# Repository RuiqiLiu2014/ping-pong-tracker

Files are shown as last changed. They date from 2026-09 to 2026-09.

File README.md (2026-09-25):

# Ping Pong Tracker

A ping pong paddle motion tracker, attached to the base of the handle, that sends 6-axis IMU data to a phone app at 1660 Hz via BLE. The phone app saves and displays the data in a readable format, showing hit time, paddle speed, brushing percentage, and more for every shot, allowing users to easily analyze their shot quality and find shortcomings in their swings.

---

## Demo

Watch the video below for a short demo.
<p align="center">
  <a href="https://youtu.be/olZcyWfupK0">
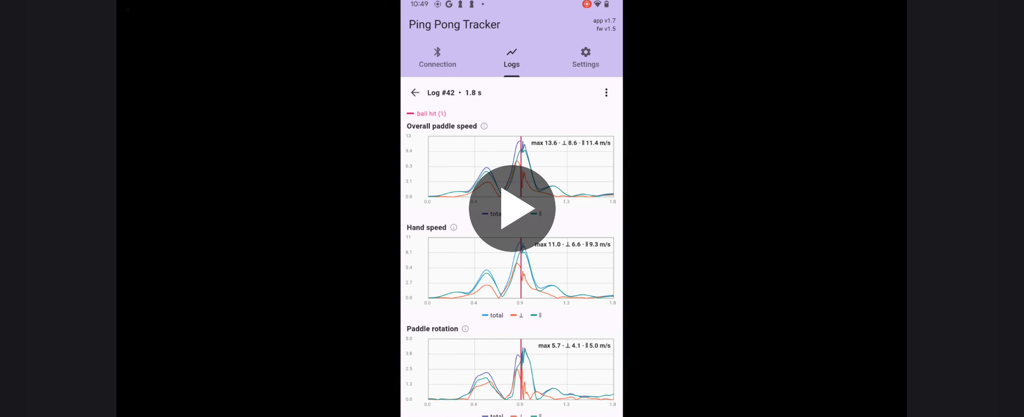
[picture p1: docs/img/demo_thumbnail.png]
Ping Pong Tracker Demo — click to watch
    
  </a>
</p>

---

## Overview

There are sports trackers out there for racket sports, but they tend to be expensive, with ping pong being one of the most expensive as it generally relies on technology embedded within the paddle itself. My goal is to create a budget-friendly alternative that can still accurately track metrics like swing speed, hit timing, and spin. My tracker uses a lightweight 3D printed case, housing a XIAO nRF52840 Sense microcontroller (with onboard 6-axis IMU) soldered to a 100 mAh LiPo battery pack. The whole unit weighs ~7g and is mounted to the base of the handle, and has features as described in the next section.

---

## Features

- Accelerometer and gyroscope streaming at 1660 Hz to accurately capture swing motions
- Automatic hit detection to log data for each shot
- Manual logging mode to log practice swings
- Metrics for every log including overall paddle speed, hand speed, paddle rotation, brushing percentage, face angle, and hit timing—all displayed using interactive graphs
- Rechargeable battery pack via USB-C port
- Straightforward app interface, color themes, light and dark mode, and very flexible settings options

---

## Screenshots

<!-- 2-4 app screenshots. A table keeps them aligned. -->
| Connection screen | Calibration wizard 1 | Calibration wizard 2 |
|---|---|---|
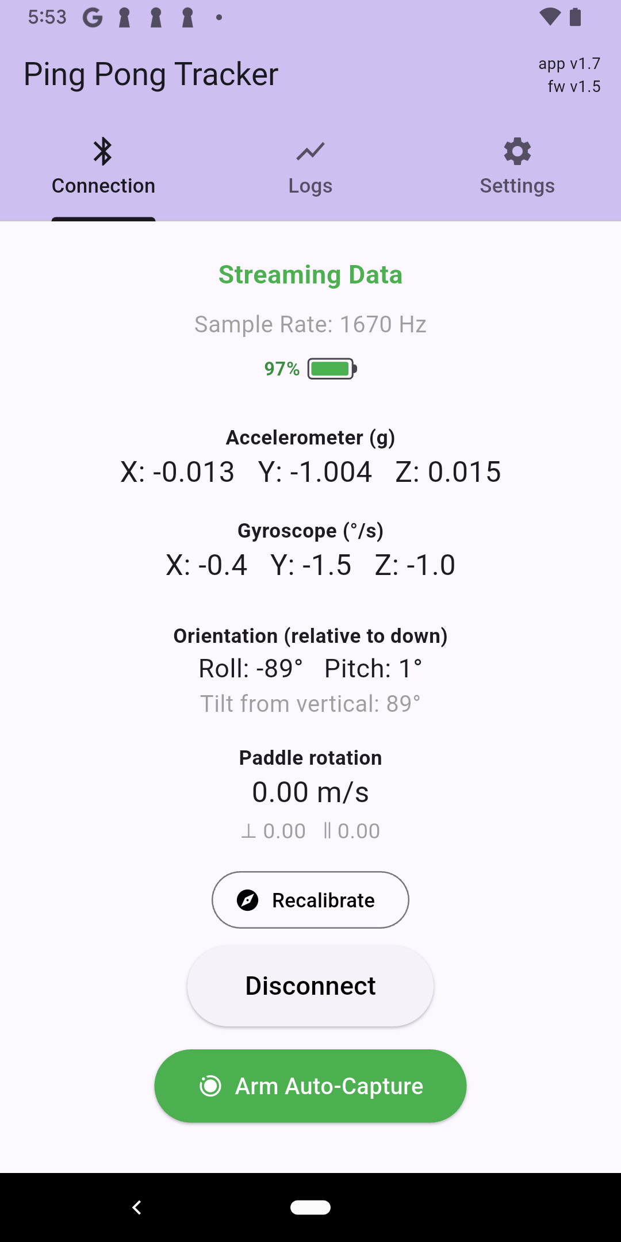
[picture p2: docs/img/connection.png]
Connection screen
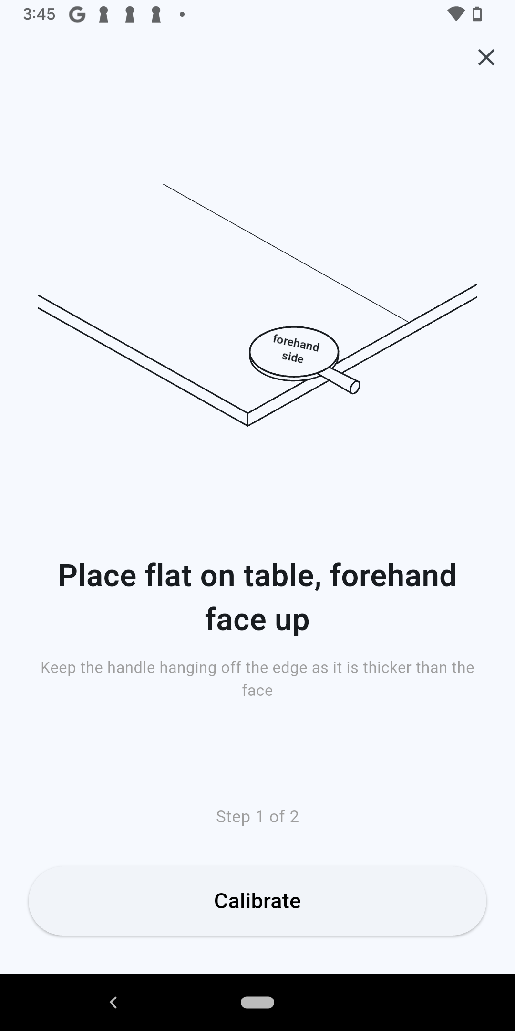
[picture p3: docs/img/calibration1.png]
Calibration wizard 1
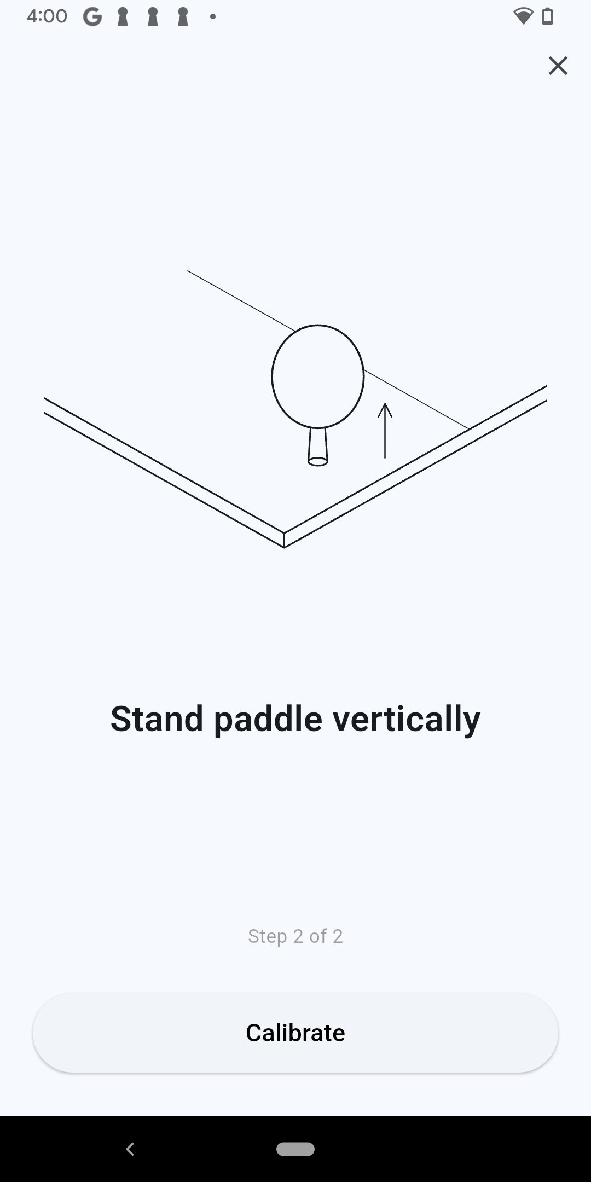
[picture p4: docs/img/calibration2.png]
Calibration wizard 2
|  |  |  |

| Logs list | Log graphs 1 | Log graphs 2 |
|---|---|---|
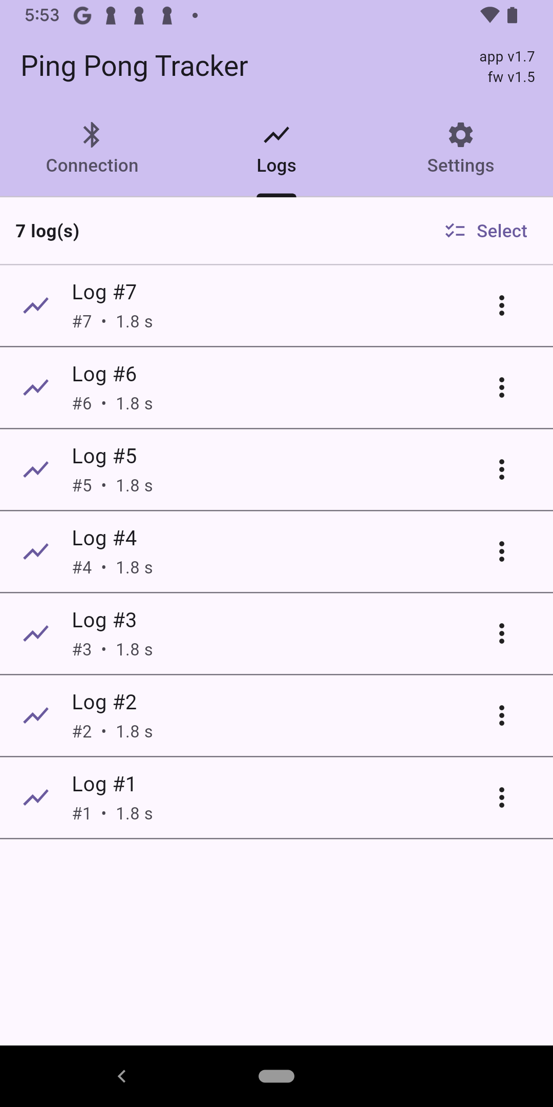
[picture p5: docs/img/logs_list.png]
Logs list
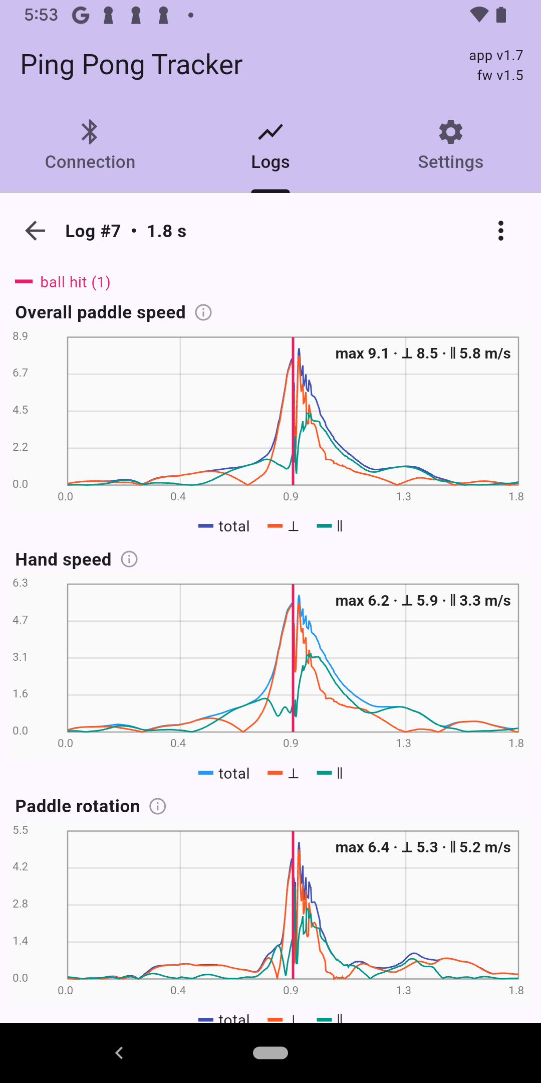
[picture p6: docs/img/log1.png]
Log graphs 1
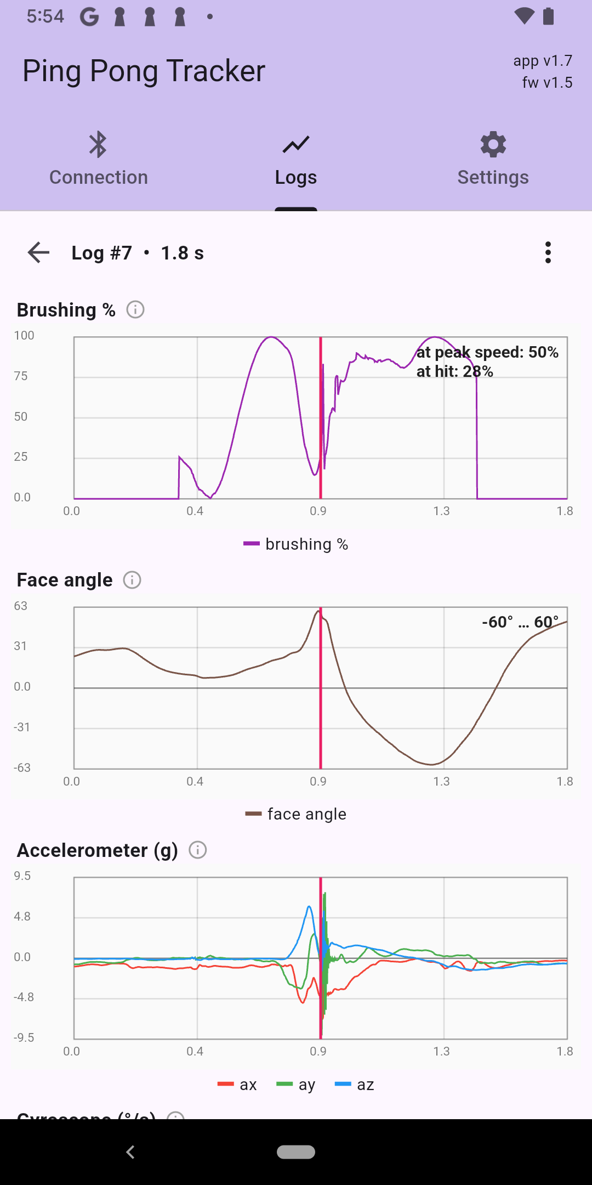
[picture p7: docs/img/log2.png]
Log graphs 2
|  |  |  |

| Settings 1 | Settings 2 | Settings 3 |
|---|---|---|
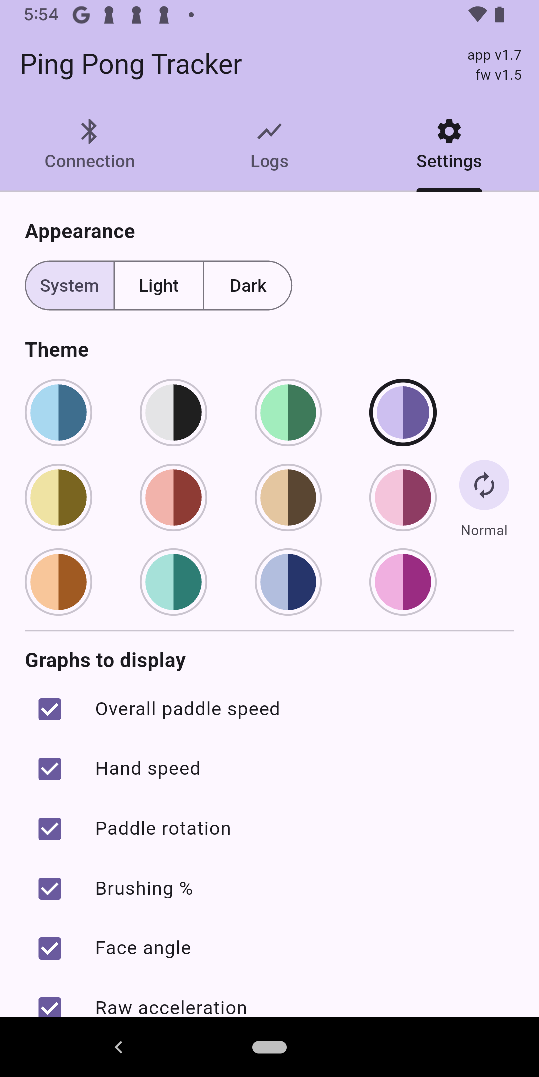
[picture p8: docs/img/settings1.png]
Settings 1
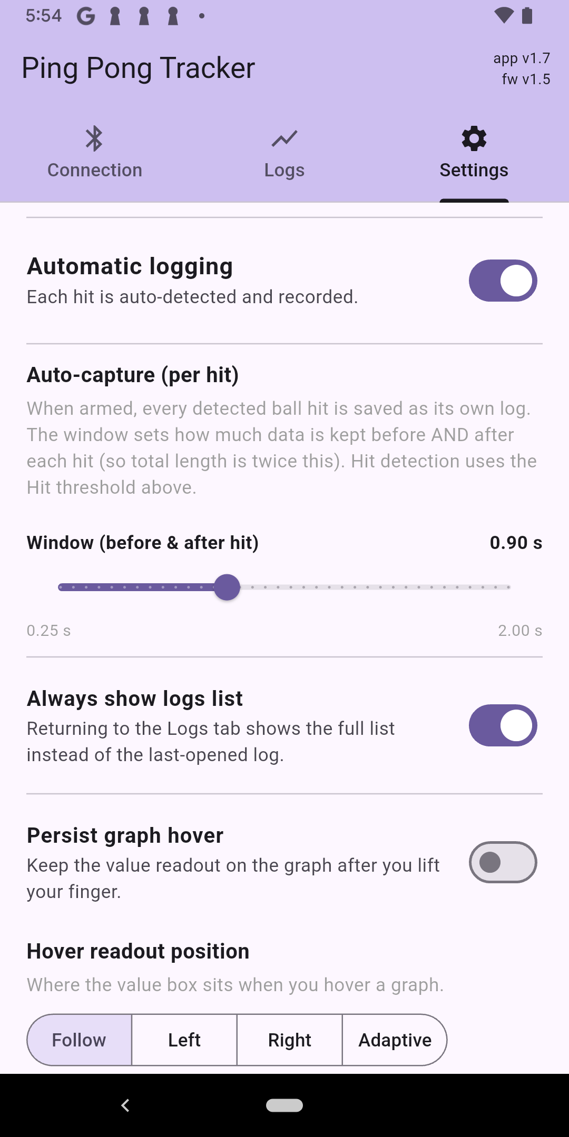
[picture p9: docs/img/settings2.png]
Settings 2
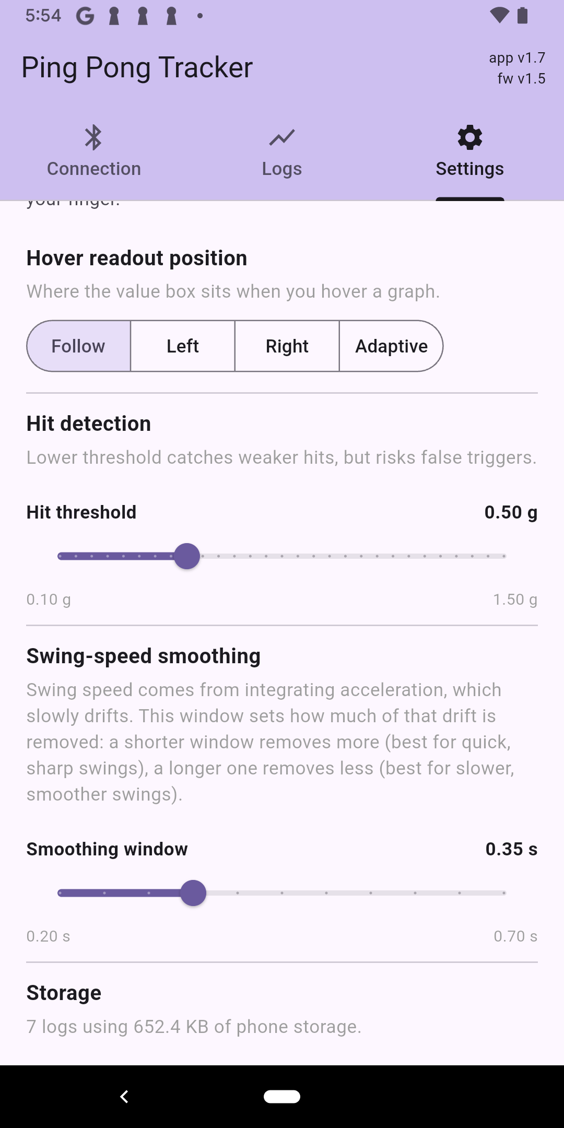
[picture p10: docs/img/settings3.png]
Settings 3
|  |  |  |

---

## How it works

The paddle is a fast, "dumb" streamer — it just samples and ships raw IMU data;
**all interpretation happens on the phone.**

```mermaid
flowchart TD
  subgraph PADDLE["Paddle unit — XIAO nRF52840 Sense"]
    IMU["LSM6DS3 IMU<br/>accel + gyro @ 1660 Hz"]
    FW["Firmware: batch samples<br/>12-byte header + up to 19×12-byte samples<br/>flush when full / every 15 ms"]
    IMU --> FW
  end
  FW -->|"BLE notify — Nordic UART<br/>~1660 Hz, batched, MTU 247"| PARSE
  subgraph PHONE["Phone app — Flutter"]
    PARSE["Parse packets<br/>rebuild µs timeline from sample index<br/>· flag dropped samples"]
    LIVE["Live readouts<br/>orientation + paddle rotation"]
    HIT["Hit detection<br/>2-pole ~120 Hz high-pass + envelope"]
    CAP["Auto-capture<br/>ring buffer → one log per hit (±window)"]
    ANALYZE["Per-log analysis<br/>• hand speed: ∫accel + high-pass detrend<br/>• paddle rotation: ω×r drift-free<br/>• overall = hand + rotation → ⟂/∥ split → brushing %<br/>• face angle vs vertical"]
    STORE["Store &amp; view<br/>interactive graphs · CSV / ZIP export"]
    CAL["Session calibration<br/>2 poses → face normal + lever direction"]
    PARSE --> LIVE
    PARSE --> HIT --> CAP --> ANALYZE --> STORE
    CAL -.-> ANALYZE
    CAL -.-> LIVE
  end
```

**End to end:**

1. **Sample** — the XIAO's LSM6DS3 reads accelerometer + gyroscope at 1660 Hz.
2. **Batch & stream** — the firmware packs samples into BLE notifications over the Nordic UART service: a 12-byte header (sample index, timestamp, battery, count, cell mV) plus up to 19 samples (6× int16 each), flushed when the buffer fills or every 15 ms, sized to the negotiated MTU and ~7.5–15 ms connection interval.
3. **Parse** — the phone rebuilds an absolute microsecond timeline from the per-sample index, so a lost packet shows up as a time gap and is flagged as dropped samples; raw counts are scaled to g and °/s.
4. **Detect hits** — a 2-pole ~120 Hz high-pass plus an envelope follower isolates the ball's high-frequency impact "ring" from low-frequency swing motion and fires once per hit.
5. **Capture** — in auto mode a ring buffer holds the last few seconds, so each hit is cut into its own log (a window before and after the impact).
6. **Analyze each log** — replaying its samples yields **hand speed** by integrating gravity-removed acceleration and high-pass-detrending the drift, and drift-free **paddle rotation** from ω×r; combined, these give the overall paddle speed, which the session calibration splits into perpendicular (closing) and parallel (brushing) parts to yield the **brushing percentage**; plus the **face angle** relative to the vertical.
7. **Store & export** — logs are saved as binary files and shown as interactive graphs, exportable to CSV/ZIP.

A quick two-pose calibration at the start of each session fixes the paddle's face normal and lever direction; these are **frozen into each log**, so metrics never shift if you recalibrate later.

---

## Technical highlights

- The 6-axis IMU streams at its maximum (hardware constrained) frequency of 1660 Hz via BLE to the phone app, packaged with timestamps. App notifies the user of any dropped data packets.
- Speed is calculated by integrating accelerometer data and combining with gyroscope data. Accelerometer data contains natural drift when integrated, which is fixed by a centered moving average high-pass.
- The app has a calibration feature that is done at the start of each session, which calibrates by measuring gravitational acceleration in two paddle positions and allows for data such as face angle.
- The app uses a 2-pole high pass filter to determine when the ball was hit by detecting high-frequency paddle vibrations and records these in each log, enabling the automatic logging feature that records one log per hit. This also enables the ability to analyze swing quality by looking at points of maximum speed and spin generation compared to hit timing.

---

## Hardware

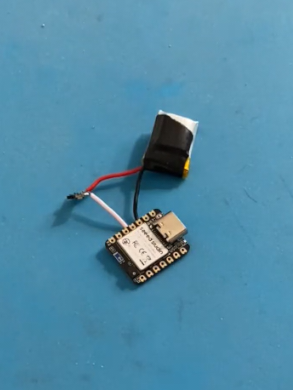
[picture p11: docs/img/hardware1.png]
Hardware 1
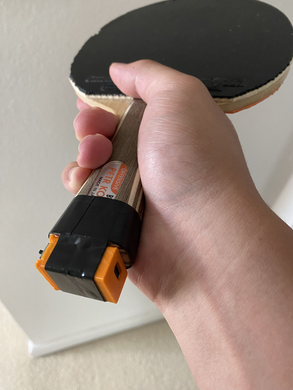
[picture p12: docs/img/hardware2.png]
Hardware 2
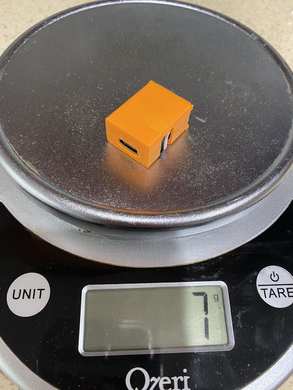
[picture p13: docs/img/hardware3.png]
Hardware 3
|  |  |  |
|---|---|---|

**Parts list**

| Part | Notes | Link |
|---|---|---|
| XIAO nRF52840 Sense | microcontroller with 6-axis IMU | https://www.amazon.com/dp/B0DJ6PZGB7 |
| 100 mAh LiPo Battery Pack | rechargeable battery pack to power the microcontroller | https://www.amazon.com/dp/B083NWXLTK |
| 1P2T Mini Slide Switch | switch to turn the unit on and off | https://www.amazon.com/dp/B01N25FBWD |

**3D printed mount (optional):** STL files for the case and lid are in [`stls/`](stls/) (`case.stl`, `lid.stl`). The printed mount is optional — it houses the board and battery and attaches to the base of the handle, but you can also secure the electronics with electrical tape.

---

## Assembly

Watch the video below for assembly instructions, then move on to **Getting started**.
<p align="center">
  <a href="https://youtu.be/WwMqLt4rDPo">
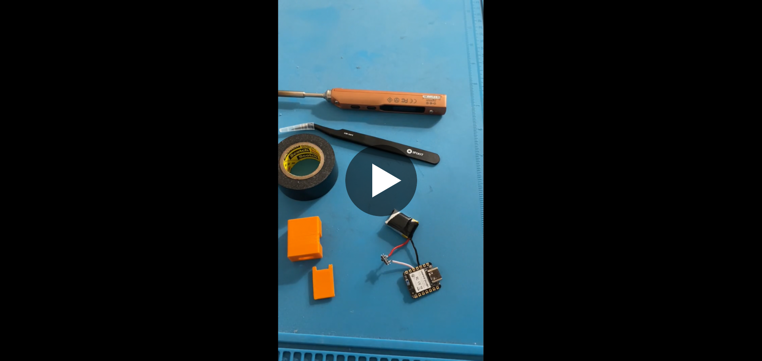
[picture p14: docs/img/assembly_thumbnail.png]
Ping Pong Tracker Assembly Instructions — click to watch
    
  </a>
</p>

---

## Getting started

1. **Flash the firmware** — download the latest **`.uf2`** from the [Releases page](https://github.com/RuiqiLiu2014/ping-pong-tracker/releases). Plug the board into your computer with a USB-C data cable and double-tap the reset button to enter bootloader mode (a `XIAO-SENSE` drive appears). Drag the `.uf2` onto that drive; it flashes and reboots automatically.
2. **Install the app** — choose your platform:
   1. **Android** — download the latest **`.apk`** from the [Releases page](https://github.com/RuiqiLiu2014/ping-pong-tracker/releases) and open it to install (allow "install from unknown sources" if prompted). To install from source code, download the Flutter SDK and run "flutter run --release" from the app folder.
   2. **iOS** — build from source on a Mac with Xcode: clone this repo, then run `cd app && flutter build ipa`, or open `ios/Runner.xcworkspace`, select your signing team, and run it to your iPhone (requires Xcode + your Apple ID for signing).
3. **Power on** — mount the board at the base of the paddle handle and flip the switch on; the LED blinks blue while it looks for the app.
4. **Connect & calibrate** — open the app, tap **Connect to Paddle**, then **Calibrate** and follow the two-pose wizard.
5. **Play** — start swinging. Each hit is auto-detected and logged; open a log to see speed, brushing percentage, and face angle. Adjust settings and themes as desired. Read the user guide below for details.

---

## User guide

**Power & charging**
- Flip the switch on the case to turn the board on.
- **The board only charges while the switch is ON.** Flip it on, then plug in USB-C — the LED turns green (blinking while charging, solid when full). Charging pauses data streaming.

**LED reference**

| LED | Meaning |
|---|---|
| Blinking blue | Searching for the app |
| Solid blue | Connected to the app |
| Blinking green | Charging |
| Solid green | Done charging |
| Alternating green/red | Plugged in but not charging (flip the switch to charge) |
| Blinking red | Battery low, searching for the app |
| Solid red | Battery low, connected to the app |

**Using the app**
- **Calibrate** at the start of each session (two quick poses) for accurate speed and angle.
- **Auto-capture** (default): every detected hit becomes its own log. Switch to manual logging mode if needed.
- **Manual logging**: for practice swings with no ball — start/stop recording yourself (toggle in Settings).
- Open a log to see swing speed, brushing percentage, face angle, and hit timing; export as CSV from the log menu.

---

## Repository structure

- app: contains the flutter app
- calibration_drawings: contains SVG files for calibration wizard images
- docs/img: contains images used in this README
- firmware: contains firmware deployed to the board for data collection
- stls: contains STL files for 3D printed case

---

## Future steps

- Implement a TinyML model to classify swings, allowing for grouping logs in the app based on swing type and better analysis among swings. Allows for focused improvement of certain swings.
- Improved metrics and in-app analysis of multiple logs.
- Use dual-endpoint ZUPT and direction-reversal zeroing for more accurate speed integration.
- Add a phone camera with YOLO to track the paddle frame by frame, allowing for more accurate metrics and live swing analysis.
- Add a live AI coach feature to the app.

---

## License

This project is licensed under the MIT License — see [LICENSE](LICENSE) for details.

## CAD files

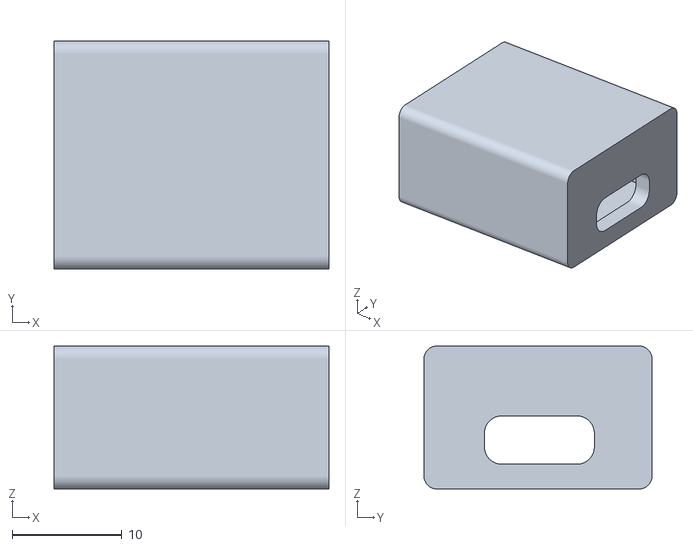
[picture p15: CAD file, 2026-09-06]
stls/case.stl
25.0 x 20.8 x 13.0

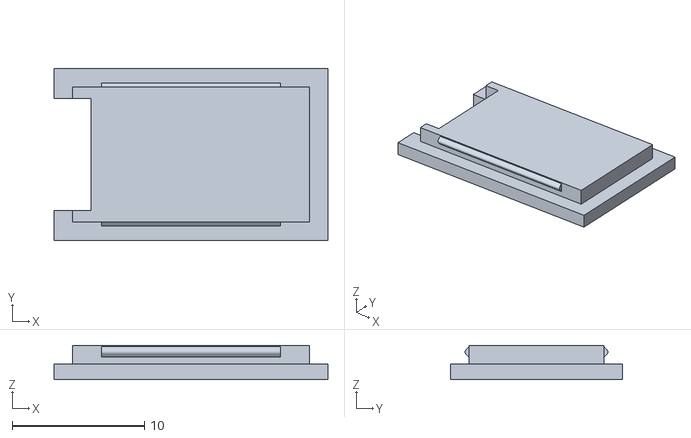
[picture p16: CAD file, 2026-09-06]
stls/lid.stl
20.8 x 13.0 x 2.60

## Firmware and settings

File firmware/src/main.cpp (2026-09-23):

#include <Arduino.h>
#include <bluefruit.h>   // Adafruit Bluefruit (SoftDevice S140) BLE stack
#include "LSM6DS3.h"
#include "Wire.h"

// =====================================================
// IMU  (LSM6DS3TR-C, internal I2C bus = Wire1 on the XIAO Sense)
// The Seeed library remaps Wire->Wire1 when TARGET_SEEED_XIAO_NRF52840_SENSE
// is defined; we set that macro in platformio.ini for the Adafruit core.
// =====================================================
LSM6DS3 myIMU(I2C_MODE, 0x6A);

#define LSM6DS3_STATUS_REG 0x1E   // bit0 XLDA (accel new), bit1 GDA (gyro new)
#define LSM6DS3_OUTX_L_G   0x22   // gx,gy,gz,ax,ay,az are contiguous 0x22..0x2D

// =====================================================
// BLE - Nordic UART UUIDs (little-endian 128-bit, same as the app expects)
//   service 6E400001-..., TX (notify) 6E400003-...
// =====================================================
const uint8_t UART_SERVICE_UUID[16] = {
  0x9E, 0xCA, 0xDC, 0x24, 0x0E, 0xE5, 0xA9, 0xE0,
  0x93, 0xF3, 0xA3, 0xB5, 0x01, 0x00, 0x40, 0x6E};
const uint8_t UART_TX_UUID[16] = {
  0x9E, 0xCA, 0xDC, 0x24, 0x0E, 0xE5, 0xA9, 0xE0,
  0x93, 0xF3, 0xA3, 0xB5, 0x03, 0x00, 0x40, 0x6E};
// Firmware version string, exposed as a READ characteristic (UUID ...0004...)
// so the app can show it on connect. Bump on firmware changes (1.0, 1.1, ...).
#define FW_VERSION "1.6"
const uint8_t UART_VER_UUID[16] = {
  0x9E, 0xCA, 0xDC, 0x24, 0x0E, 0xE5, 0xA9, 0xE0,
  0x93, 0xF3, 0xA3, 0xB5, 0x04, 0x00, 0x40, 0x6E};

BLEService        uartService(UART_SERVICE_UUID);
BLECharacteristic txChar(UART_TX_UUID);
BLECharacteristic verChar(UART_VER_UUID);

// =====================================================
// Batched notification buffer (firmware v1.1 packet)
//   bytes 0..3 : uint32 LE  first-sample index (cumulative; resets on connect)
//   bytes 4..7 : uint32 LE  first-sample timestamp = micros() from the chip
//   byte  8    : battery % in bits 0..6; bit 7 = charging LED state (fw >= 1.5:
//                set while charging or topped off, clear when plugged but NOT
//                charging — e.g. the on/off switch is off. fw 1.3-1.4 set it
//                whenever plugged in.)
//   byte  9    : number of samples N in this packet
//   bytes 10..11 : uint16 LE  battery millivolts (fw >= 1.3; 0 if unread)
//   then N * 12 bytes: int16 LE  ax, ay, az, gx, gy, gz  (raw sensor counts)
// The 12-byte header lets the app reconstruct exact per-sample times from the
// chip clock and detect dropped samples (a jump in the index). The app applies
// the LSM6DS3 sensitivities (accel +/-16g, gyro 2000 dps).
// Byte 8's coarse % stays for backward compatibility; fw >= 1.3 also sends the
// raw millivolts (bytes 10..11) so the app can map SoC on a real LiPo curve at
// sub-1% resolution. While plugged into USB (fw >= 1.3) the board does NOT stream
// IMU data: it sends a header-only status packet (N = 0, plus the mV) ~1 Hz
// instead. The app treats any N = 0 packet as this plugged/no-stream state, and
// reads bit 7 to show either "charging" (set) or "not charging" (clear).
// =====================================================
#define PKT_HEADER    12
#define MAX_SAMPLES   19              // 12 + 19*12 = 240 bytes, fits a 247-byte MTU
#define SAMPLE_BYTES  12
static uint8_t  txbuf[PKT_HEADER + MAX_SAMPLES * SAMPLE_BYTES];
static uint16_t sampleCount = 0;
static uint32_t lastFlushMs = 0;
static uint32_t sampleIndexTotal = 0;  // cumulative samples since connect
static uint32_t packetFirstIndex = 0;  // index of this packet's first sample
static uint32_t packetFirstMicros = 0; // micros() of this packet's first sample

// Charge-status input from the BQ25101 (the line that drives the on-board CHG
// LED). P0.17 / Arduino pin 23 on the XIAO nRF52840; it reads LOW while the
// battery is charging and HIGH otherwise (open-drain, so we pull it up).
#define PIN_CHARGE_STATE 23

volatile bool connected = false;
int      batteryPct   = 100;
uint16_t batteryMv    = 0;       // raw cell millivolts (fw >= 1.3 packet field)
uint32_t lastBattUs   = 0;
bool     pluggedIn    = false;   // VBUS present (USB 5 V) — gates streaming + LED
bool     chargeActive = false;   // CHG pin LOW = charger actively pushing current
uint32_t lastStatusMs = 0;       // cadence for charging-status packets

// ---- Status LED (onboard user RGB, driven manually; Bluefruit auto-LED off) ----
// Colour encodes power state; blink encodes activity. On this board the dies are
// active-LOW (pin LOW = lit) — the variant's LED_STATE_ON is wrong, so we don't
// use it. Only one die is ever lit, so colours never blend.
//   Plugged in: green — blink while charging, solid once full / charge-complete.
//   Plugged but NOT charging with no healthy cell reading (e.g. the on/off switch
//     is off, so the battery is disconnected): alternating green/red as a
//     "flip the switch" reminder.
//   On battery: blue (ok) or red (low) — blink while BLE-searching, solid when
//               BLE-connected.  (off only when powered down)
#define LED_BLINK_MS   300   // half-period of the searching / charging flash
#define BATT_LOW_MV   3730   // low-battery: matches the app's red threshold (LiPo 20%)
#define BATT_LOW_CLR  3770   // hysteresis: clear "low" only once back above this
// Plugged + not charging + VBAT below this => treat as "not charging" (typically
// the on/off switch is off, so no real cell is on the divider) rather than a
// completed charge. Set near a full cell so a merely-high battery with the switch
// off still nudges the user: the app stretches its LiPo curve, so this ~4.10 V
// maps to ~95% shown — only a nearly-full cell reads solid-green "charge done".
#define BATT_PRESENT_MV 4100
bool lowBatt = false;
enum LedColor { LED_C_OFF, LED_C_BLUE, LED_C_GREEN, LED_C_RED };

void connectCallback(uint16_t connHandle) {
  BLEConnection* conn = Bluefruit.Connection(connHandle);
  // Everything that maximizes throughput so a high sample rate can stream:
  conn->requestPHY();                     // 2 Mbps PHY
  conn->requestDataLengthUpdate();        // BLE data length extension
  conn->requestMtuExchange(247);          // large MTU -> big batched packets
  conn->requestConnectionParameter(6);    // 6 * 1.25 ms = 7.5 ms interval
  sampleIndexTotal = 0;                    // restart the sample counter per link
  connected = true;
}

void disconnectCallback(uint16_t connHandle, uint8_t reason) {
  (void)connHandle;
  (void)reason;
  connected = false;
  sampleCount = 0;
}

// Read the battery divider (oversampled) into batteryMv + coarse batteryPct.
// Called once in setup() to prime the values, then every 2 s from loop(), so a
// packet never ships an unread mV of 0 (which the app would map to a stuck 0%).
void sampleBattery() {
  digitalWrite(VBAT_ENABLE, LOW);   // enable divider (active low)
  delay(2);
  // Oversample: one analogRead carries the full ADC noise, so average 64 of
  // them (~8x less noise, still well under 1 ms) before scaling to volts.
  uint32_t acc = 0;
  for (int i = 0; i < 64; i++) acc += analogRead(PIN_VBAT);
  digitalWrite(VBAT_ENABLE, HIGH);
  float rawADC = acc / 64.0f;
  float vbat = (rawADC / 4096.0f) * 3.6f * (1510.0f / 510.0f);
  batteryMv = (uint16_t)(vbat * 1000.0f);   // raw mV -> app maps SoC on a LiPo curve
  // Coarse % kept for older apps; the app prefers the mV field when present.
  int pct = (int)(((vbat - 3.2f) / (4.2f - 3.2f)) * 100.0f);
  batteryPct = constrain(pct, 0, 100);
}

// Per-colour lit level (active-low: lower = brighter).
static inline uint8_t ledLit(LedColor c) {
  switch (c) {
    case LED_C_GREEN: return 0;
    case LED_C_RED:   return 64;
    default:          return 128;
  }
}

// Light exactly one colour (or none) — one die at a time, so nothing blends.
void setStatusLed(LedColor c, bool on) {
  uint8_t v = on ? ledLit(c) : 255;   // 255 = off (held HIGH)
  analogWrite(LED_RED,   c == LED_C_RED   ? v : 255);
  analogWrite(LED_GREEN, c == LED_C_GREEN ? v : 255);
  analogWrite(LED_BLUE,  c == LED_C_BLUE  ? v : 255);
}

// Status-LED state machine, polled every loop. Plugged in => green (blink while
// charging, solid once full). On battery => blue/red for ok/low, blinking while
// searching for BLE and solid once connected. Only touches the pins on change.
void updateStatusLed() {
  if (batteryMv <= BATT_LOW_MV) lowBatt = true;
  else if (batteryMv >= BATT_LOW_CLR) lowBatt = false;

  const bool blink = ((millis() / LED_BLINK_MS) & 1) == 0;
  LedColor color;
  bool on;
  if (pluggedIn) {
    if (chargeActive) {
      color = LED_C_GREEN;              // actively charging -> blinking green
      on = blink;
    } else if (batteryMv >= BATT_PRESENT_MV) {
      color = LED_C_GREEN;              // charge complete -> solid green
      on = true;
    } else {
      // Plugged, not charging, and no healthy cell reading: the switch is off
      // (battery disconnected). Alternate green/red as a "flip the switch" nudge.
      color = blink ? LED_C_GREEN : LED_C_RED;
      on = true;
    }
  } else {
    color = lowBatt ? LED_C_RED : LED_C_BLUE;
    on = connected ? true : blink;      // solid when connected, blink when searching
  }

  static LedColor lastColor = LED_C_OFF;
  static bool lastOn = false;
  static bool inited = false;
  if (inited && color == lastColor && on == lastOn) return;
  lastColor = color;
  lastOn = on;
  inited = true;
  setStatusLed(color, on);
}

void setup() {
  // Let the LSM6DS3 finish its power-on boot (~15-35 ms) before the first I2C
  // access. The old `while (!Serial ...)` wait used to provide this cushion
  // incidentally (a full 2 s on battery); without it, myIMU.begin() can run
  // before the IMU is ready on a cold boot and hang the board on the check below.
  delay(100);

  // ---- IMU: configure for the maximum ODR both sensors share (1660 Hz) ----
  myIMU.settings.gyroEnabled      = 1;
  myIMU.settings.gyroRange        = 2000;   // deg/s
  myIMU.settings.gyroSampleRate   = 1660;   // Hz (gyro max)
  myIMU.settings.gyroFifoEnabled  = 0;
  myIMU.settings.accelEnabled     = 1;
  myIMU.settings.accelRange       = 16;     // g
  myIMU.settings.accelSampleRate  = 1660;   // Hz
  myIMU.settings.accelFifoEnabled = 0;
  myIMU.settings.tempEnabled      = 0;
  if (myIMU.begin() != 0) {
    while (1) {}
  }
  Wire1.setClock(400000);   // 400 kHz I2C so a 12-byte burst read is ~0.35 ms

  // ---- Battery divider (VBAT_ENABLE / PIN_VBAT provided by the variant) ----
  pinMode(PIN_VBAT, INPUT);
  pinMode(VBAT_ENABLE, OUTPUT);
  analogReadResolution(12);
  digitalWrite(VBAT_ENABLE, HIGH);   // divider off until we sample
  pinMode(PIN_CHARGE_STATE, INPUT_PULLUP);  // open-drain CHG line; LOW = charging
  sampleBattery();                          // prime batteryMv/Pct before streaming

  // ---- BLE ----
  Bluefruit.configPrphBandwidth(BANDWIDTH_MAX);   // must precede begin()
  Bluefruit.begin();
  Bluefruit.autoConnLed(false);        // we drive the RGB status LED ourselves
  setStatusLed(LED_C_OFF, false);      // dark until the first loop() state update
  Bluefruit.setTxPower(4);
  Bluefruit.setName("PaddleTrack");
  Bluefruit.Periph.setConnectCallback(connectCallback);
  Bluefruit.Periph.setDisconnectCallback(disconnectCallback);
  Bluefruit.Periph.setConnInterval(6, 12);        // 7.5 - 15 ms

  uartService.begin();                            // service first...
  txChar.setProperties(CHR_PROPS_NOTIFY);         // ...then its characteristic
  txChar.setPermission(SECMODE_OPEN, SECMODE_NO_ACCESS);
  txChar.setMaxLen(sizeof(txbuf));
  txChar.begin();

  // Firmware version, read once by the app on connect.
  verChar.setProperties(CHR_PROPS_READ);
  verChar.setPermission(SECMODE_OPEN, SECMODE_NO_ACCESS);
  verChar.setMaxLen(8);
  verChar.begin();
  verChar.write(FW_VERSION, sizeof(FW_VERSION) - 1);

  Bluefruit.Advertising.addFlags(BLE_GAP_ADV_FLAGS_LE_ONLY_GENERAL_DISC_MODE);
  Bluefruit.Advertising.addTxPower();
  Bluefruit.Advertising.addService(uartService);
  Bluefruit.ScanResponse.addName();               // name lives in scan response
  Bluefruit.Advertising.restartOnDisconnect(true);
  Bluefruit.Advertising.setInterval(32, 244);     // units of 0.625 ms
  Bluefruit.Advertising.setFastTimeout(30);
  Bluefruit.Advertising.start(0);                 // advertise forever

  lastFlushMs = millis();
  lastBattUs  = micros();
}

void loop() {
  // ---- Battery every 2 s ----
  uint32_t nowUs = micros();
  if (nowUs - lastBattUs > 2000000UL) {
    sampleBattery();
    lastBattUs = nowUs;
  }

  // "Plugged in" = USB 5 V present on VBUS, independent of whether the charger
  // is still pushing current or has already topped off (the CHG pin goes HIGH at
  // charge-complete even while still plugged). We gate on VBUS so a full-but-
  // plugged board is still treated as charging: it never streams while plugged,
  // which frees the charge current AND — critically — avoids the streaming load
  // sagging VBAT. That sag used to get latched by the app's never-rise clamp and
  // crater the reported %. CHG pin is left wired but no longer gates streaming.
  pluggedIn = (NRF_POWER->USBREGSTATUS & POWER_USBREGSTATUS_VBUSDETECT_Msk) != 0;
  chargeActive = (digitalRead(PIN_CHARGE_STATE) == LOW);  // charger pushing current
  updateStatusLed();

  if (!connected) {
    delay(1);
    return;
  }

  // ---- Plugged in: do NOT stream IMU. Send a small header-only status packet
  // ~1 Hz (N = 0, battery byte bit 7 set) so the app shows a dedicated charging
  // state and a live battery %. Not streaming frees the ~50 mA charge current AND
  // keeps VBAT off-load so the reported % stays true (no sag to latch). ----
  if (pluggedIn) {
    sampleCount = 0;                        // drop any half-filled stream batch
    uint32_t nowMs = millis();
    if (nowMs - lastStatusMs >= 1000) {     // ~1 Hz status while plugged (low rate)
      memset(txbuf, 0, PKT_HEADER);
      // bit7 mirrors the green charging LED: set while actively charging or
      // topped off, clear when plugged but not charging (switch off). N = 0
      // marks this as a status (no-stream) packet regardless of bit7.
      const bool chargingLed = chargeActive || (batteryMv >= BATT_PRESENT_MV);
      txbuf[8] = (uint8_t)(batteryPct & 0x7F);
      if (chargingLed) txbuf[8] |= 0x80;
      txbuf[9] = 0;                             // N = 0 (no samples)
      memcpy(&txbuf[10], &batteryMv, 2);        // raw cell mV
      txChar.notify(txbuf, PKT_HEADER);
      lastStatusMs = nowMs;
    }
    delay(5);
    return;
  }

  // ---- Capture a new IMU sample when the sensor flags data-ready ----
  uint8_t status = 0;
  myIMU.readRegister(&status, LSM6DS3_STATUS_REG);
  if ((status & 0x01) && sampleCount < MAX_SAMPLES) {   // XLDA: fresh accel data
    uint8_t raw[12];
    if (myIMU.readRegisterRegion(raw, LSM6DS3_OUTX_L_G, 12) == 0) {
      if (sampleCount == 0) {                 // stamp this packet's first sample
        packetFirstMicros = micros();
        packetFirstIndex  = sampleIndexTotal;
      }
      // burst layout is gyro(0..5) then accel(6..11); repack accel-first
      uint16_t off = PKT_HEADER + sampleCount * SAMPLE_BYTES;
      memcpy(&txbuf[off + 0], &raw[6], 6);   // ax, ay, az
      memcpy(&txbuf[off + 6], &raw[0], 6);   // gx, gy, gz
      sampleCount++;
      sampleIndexTotal++;
    }
  }

  // ---- Flush a batched notification when full or after a short latency cap ----
  BLEConnection* conn = Bluefruit.Connection(0);
  uint16_t mtu = conn ? conn->getMtu() : 23;
  uint16_t cap = (mtu > 5) ? ((mtu - 3 - PKT_HEADER) / SAMPLE_BYTES) : 1;
  if (cap > MAX_SAMPLES) cap = MAX_SAMPLES;
  if (cap < 1) cap = 1;

  uint32_t nowMs = millis();
  bool full    = sampleCount >= cap;
  bool timeout = sampleCount > 0 && (nowMs - lastFlushMs >= 15);
  if (full || timeout) {
    memcpy(&txbuf[0], &packetFirstIndex, 4);   // uint32 LE first-sample index
    memcpy(&txbuf[4], &packetFirstMicros, 4);  // uint32 LE first-sample micros
    txbuf[8] = (uint8_t)batteryPct;
    txbuf[9] = (uint8_t)sampleCount;
    memcpy(&txbuf[10], &batteryMv, 2);         // raw cell mV
    uint16_t len = PKT_HEADER + sampleCount * SAMPLE_BYTES;
    if (txChar.notify(txbuf, len)) {
      sampleCount = 0;
      lastFlushMs = nowMs;
    } else if (sampleCount >= MAX_SAMPLES) {
      // notify queue full and buffer maxed: drop oldest batch to keep sampling
      sampleCount = 0;
      lastFlushMs = nowMs;
    }
  }
}

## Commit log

2026-07-18 working arduino library version
2026-07-19 working orientation and velocity tracker
2026-07-19 finalize velocity measurements
2026-07-27 add hit detector, change app ui, untested
    [Log _1.csv, Log _10.csv, Log _11.csv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]
2026-08-15 add data
    [Log _1.csv, Log _10.csv, Log _11.csv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]
2026-08-16 app v1.1: speed calculation using gyro instead of acceleration
2026-08-23 integrate app with android back button
2026-08-24 app v1.2 complete: added parallel and perp speed graphs and forehand face up calibration
2026-08-31 qol changes
    [backhand.csv, backhand_1.csv, backhand_2.csv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]
2026-09-06 stop tracking some folders and files
    [Log _1.csv, Log _10.csv, Log _11.csv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]
2026-09-06 reorganize files into folders
    [case.stl, lid.stl]
2026-09-07 add calibration wizard and create images
2026-09-07 add svg files for calibration to app
2026-09-07 firmware and app +version, fix charging and add charging state
    [main.cpp]
2026-09-07 update app and firmware for more accurate battery reading, untested
2026-09-07 update battery time to full estimate and increase battery resolution (untested), add firmware checker in app
2026-09-08 add board state LED indication
2026-09-08 add firmware RGB status LED; fix charging-state app controls
    Firmware (fw 1.4): drive the onboard user RGB LED as a status light —
    green charging, blue on-battery, red low, blinking when searching and
    solid when connected; active-low, ~50% brightness. Also drop the
    charging-status broadcast to 1 Hz.
    App: treat the charging state as connected so the button shows
    Disconnect (and works), and disable Calibrate/logging while charging so
    only Connect/Disconnect are active.
    [main.cpp]
2026-09-08 adjust LED scheme and rescale battery level
2026-09-08 add more robust calibration validation
2026-09-08 tweak calibration wizard
2026-09-08 add drop sample counter
2026-09-09 fix charging voltage bug
    [main.cpp]
2026-09-10 fix calibration independence with logs, add face angle graph, adjust graph titles and add info popups
2026-09-10 back compatability cleanup, remove calibration initial drawings
2026-09-13 add switch not flipped charging detection to firmware
    [main.cpp]
2026-09-13 fix switch not flipped firmware detection and add to app, update readme accordingly
    [main.cpp]
2026-09-20 updating readme with assembly video
    Added a video link for assembly instructions and removed the TODO comment about building the unit.
2026-09-20 add play button to assembly thumbnail
2026-09-20 Revise screenshots in README
    Updated the screenshots section to include new calibration and settings images.
2026-09-20 Add hardware photos to README
    Updated hardware section with images of the device.
2026-09-20 update 3d printed mount section in README
    Updated description of the 3D-printed mount to specify using electrical tape for securing electronics.
2026-09-21 enforce calibration wizard on connection
2026-09-21 app version 1.7, completely force calibration on connect
2026-09-21 update calibrationwizard logic for charging
2026-09-23 remove debug prints in firmware
2026-09-24 adjust zoom levels and x-axis decimal point rounding, adjust hit numbering, move at-hit stats to outside the graph
2026-09-24 fix pan flashing bug, change indicator for dropped samples
